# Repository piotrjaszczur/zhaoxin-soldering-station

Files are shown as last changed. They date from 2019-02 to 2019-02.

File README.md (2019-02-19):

# zhaoxin-soldering-station
Project for microcontrollers course at AGH. Soldering station control unit for the Zhaoxin 936 soldering iron

The schematic and the board created for the project for the microcontrollers course at AGH. 
It was based around the "Blue Pill" STM32 Development Board with STM32f103c8t6 MCU. It provided the temperature reading based on the ADC measuring of the voltage on the soldering iron termistor. IRF4905 PMOS transistor was driven by the PWM signal with the duty cycle depending on the current temperature reading. The rotary encoder allowed to change the desired temperature and the 4 microswitches allowed to choose one of the preset 4 different temperatures.

It is planned to be used with a 24V switching power supply.

stacja schem

stacja board

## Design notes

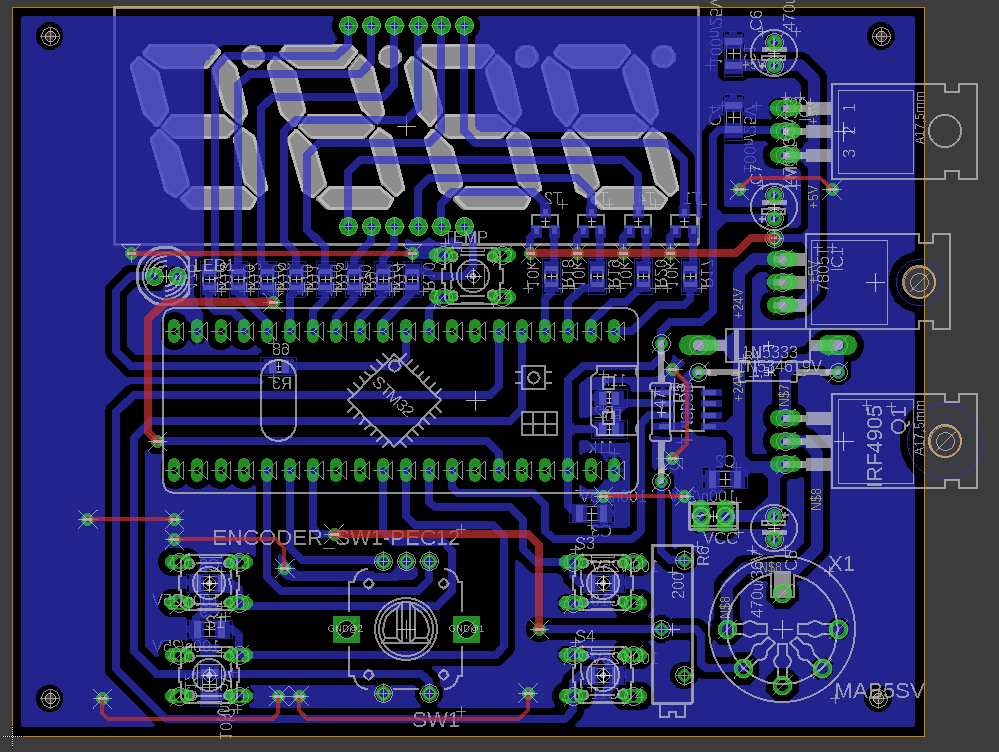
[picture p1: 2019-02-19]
stacja board.png

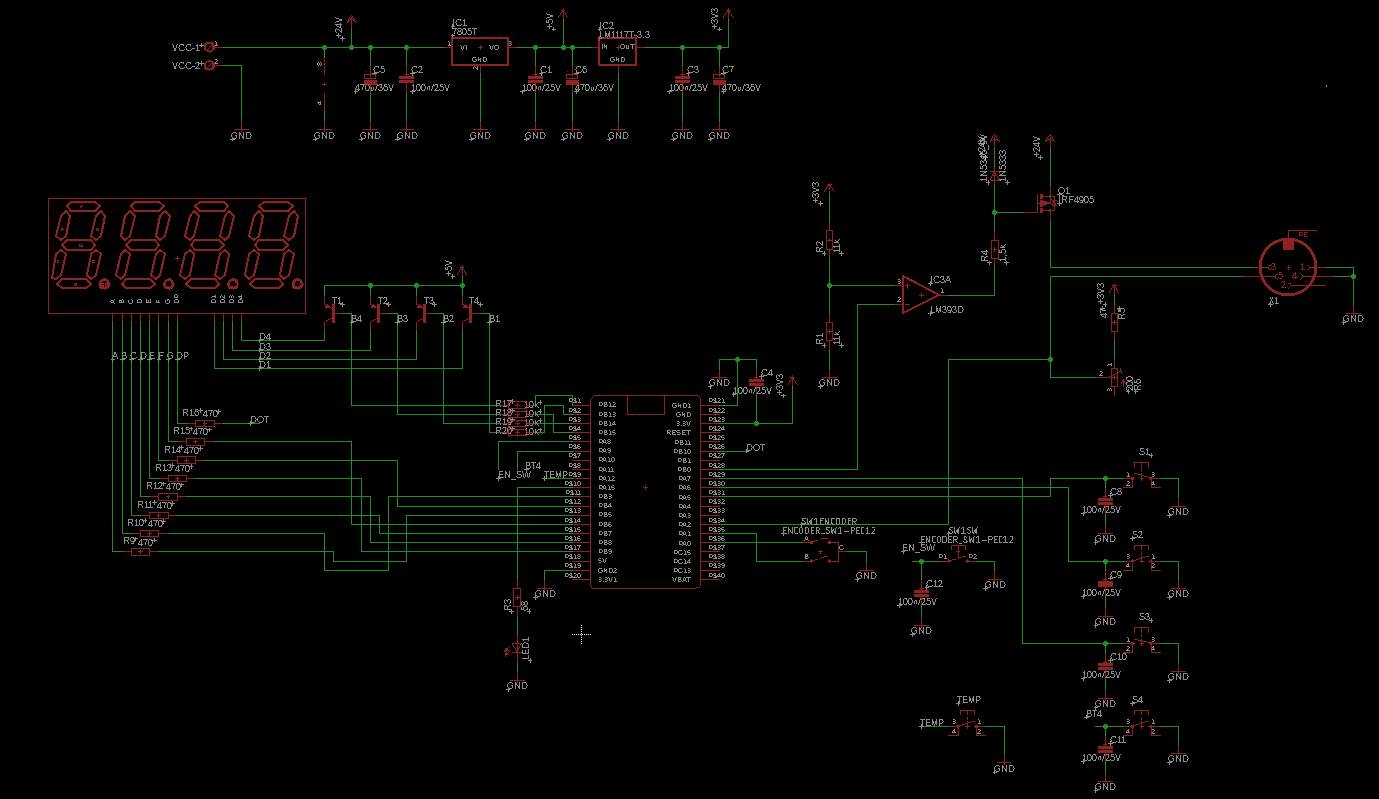
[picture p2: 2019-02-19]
stacja schem.png

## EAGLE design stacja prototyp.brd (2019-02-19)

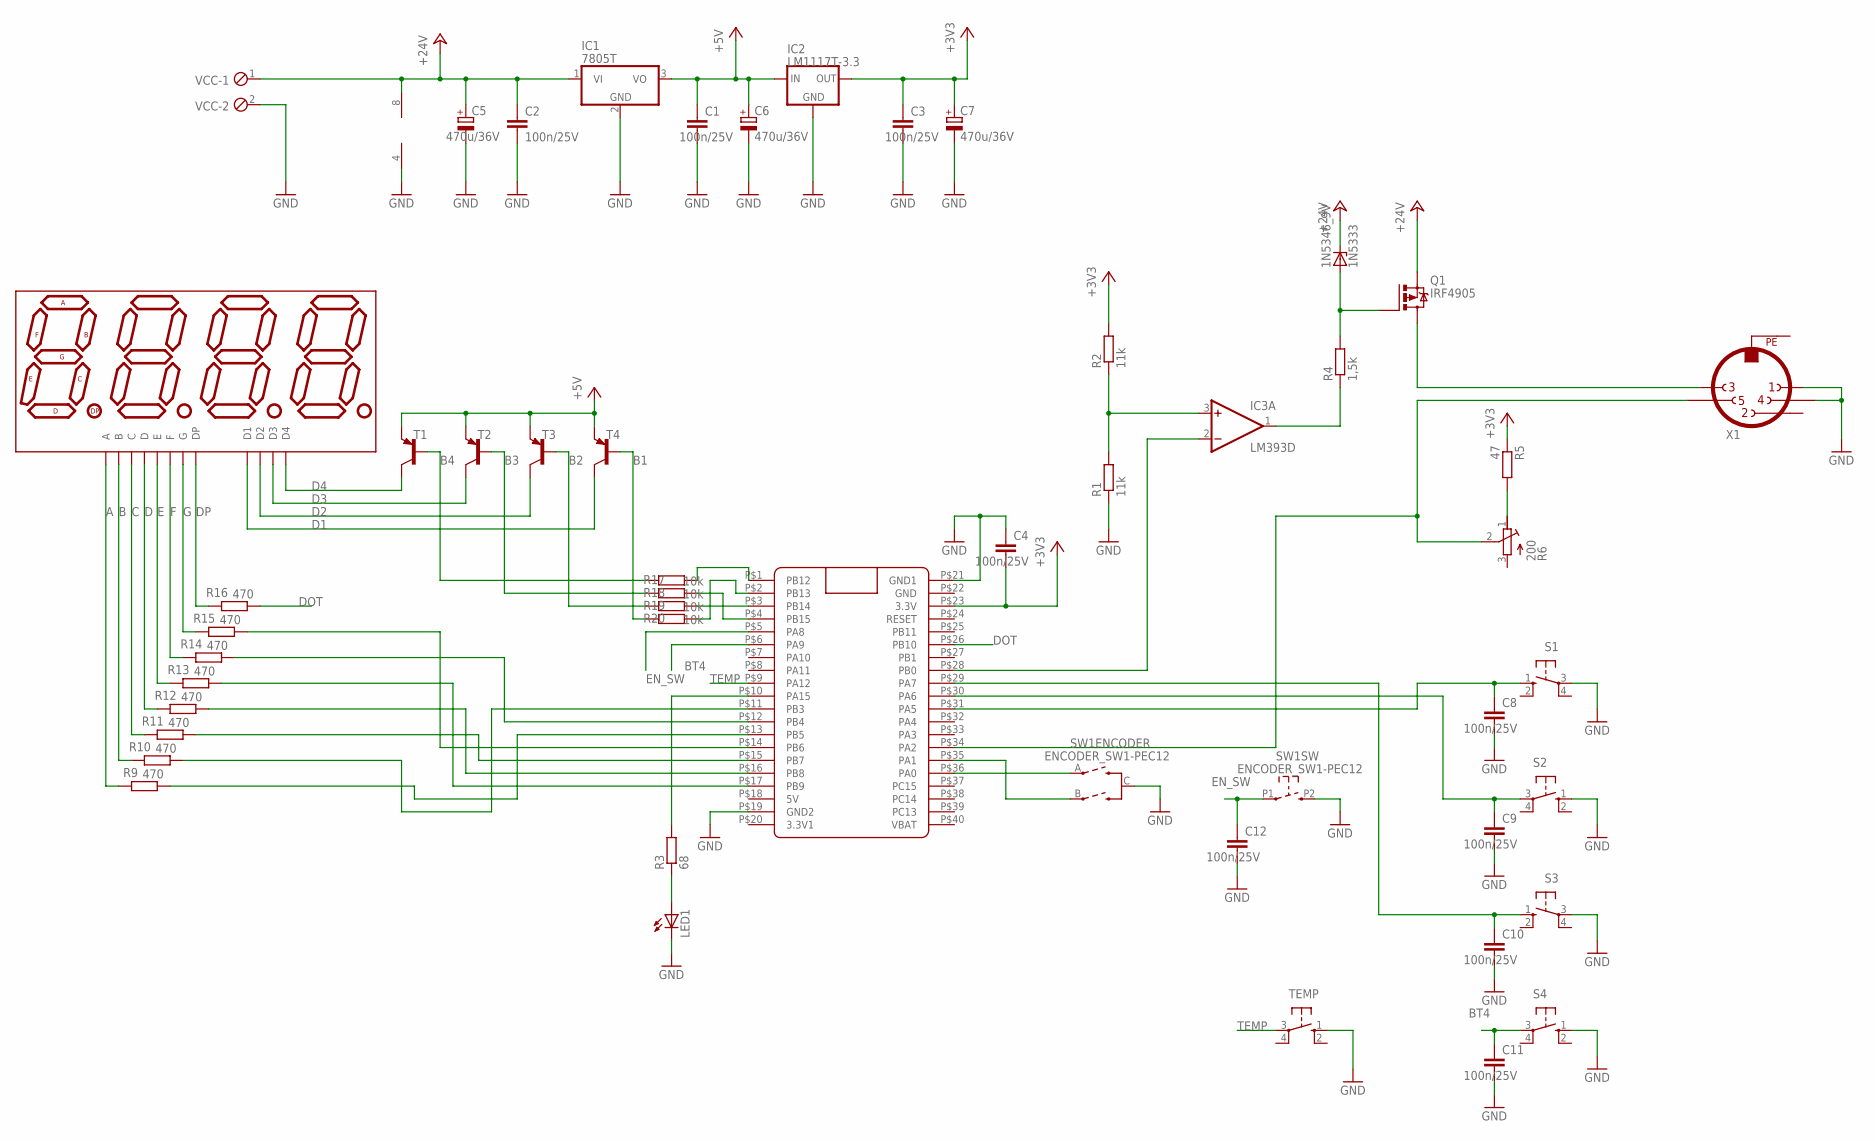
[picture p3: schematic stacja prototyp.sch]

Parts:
1N5346_9V: 1N5333; C1702-15
C1, C2, C3, C4, C8, C9, C10, C11, C12: 100n/25V; C1206
C5, C6, C7: 470u/36V; E2,5-5
DISP1: ATA8041ARBJ; 7-SEGMENT-4DIGIT-20MM
IC1: 7805T; TO220H
IC2: LM1117T-3.3; TO220
IC3: LM393D; SO08
LED1: LED5MM
Q1: IRF4905; TO220BH
R1, R2: 11k; R0805
R3: 68; R0805
R4: 1,5k; 0207/15
R5: 47; 0207/15
R6: 200; RTRIM43P
R9, R10, R11, R12, R13, R14, R15, R16: 470; M0805
R17, R18, R19, R20: 10k; M0805
S1, S2, S3, S4: 10-XX; B3F-10XX
SW1: ENCODER_SW1-PEC12; PEC12_INCREMENTAL_ENCODER
T1, T2, T3, T4: BC857B-PNP-SOT23-BEC; SOT23-BEC
TEMP: 10-XX; B3F-10XX
U$1: BLUE_PILL
VCC: MPT2; 2POL254
X1: MAB5SV

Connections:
+3V3: C3.1, C4.2, C7.+, IC2.2 (OUT), R2.2, R5.1, U$1.P$23 (3.3V)
+5V: C1.1, C6.+, IC1.3 (VO), IC2.3 (IN), T1.E, T2.E, T3.E, T4.E
+24V: 1N5346_9V.C, C2.1, C5.+, IC1.1 (VI), IC3.8 (V+), Q1.S, VCC.1
A: DISP1.11 (A), R9.2
B: DISP1.7 (B), R10.2
B1: R20.2, T4.B
B2: R19.2, T3.B
B3: R18.2, T2.B
B4: R17.2, T1.B
BT4: C11.1, S4.3, U$1.P$6 (PA9)
C: DISP1.4 (C), R11.2
D: DISP1.2 (D), R12.2
D1: DISP1.12 (D1), T4.C
D2: DISP1.9 (D2), T3.C
D3: DISP1.8 (D3), T2.C
D4: DISP1.6 (D4), T1.C
DOT: R16.1, U$1.P$26 (PB10)
DP: DISP1.3 (DP), R16.2
E: DISP1.1 (E), R13.2
EN_SW: C12.1, SW1.P1 (1), U$1.P$5 (PA8)
F: DISP1.10 (F), R14.2
G: DISP1.5 (G), R15.2
GND: C1.2, C2.2, C3.2, C4.1, C5.-, C6.-, C7.-, C8.2, C9.2, C10.2, C11.2, C12.2, IC1.2 (GND), IC2.1 (GND), IC3.4 (V-), LED1.K (C), R1.1, S1.3, S2.1 (S), S3.3, S4.1 (S), SW1.C, SW1.P2 (2), TEMP.1 (S), U$1.P$19 (GND2), U$1.P$21 (GND1), VCC.2, X1.1, X1.4
unnamed: IC3.2 (-IN), U$1.P$28 (PB0)
unnamed: C8.1, S1.1 (S), U$1.P$31 (PA5)
unnamed: C9.1, S2.3, U$1.P$30 (PA6)
unnamed: IC3.3 (+IN), R1.2, R2.1
unnamed: R6.2 (S), U$1.P$34 (PA2), X1.5
unnamed: IC3.1 (OUT), R4.1
unnamed: 1N5346_9V.A, Q1.G, R4.2
unnamed: Q1.D, X1.3
unnamed: SW1.A, U$1.P$36 (PA0)
unnamed: SW1.B, U$1.P$35 (PA1)
unnamed: LED1.A, R3.1
unnamed: R3.2, U$1.P$10 (PA15)
unnamed: R5.2, R6.1 (E)
unnamed: C10.1, S3.1 (S), U$1.P$29 (PA7)
unnamed: R18.1, U$1.P$4 (PB15)
unnamed: R19.1, U$1.P$3 (PB14)
unnamed: R17.1, U$1.P$1 (PB12)
unnamed: R20.1, U$1.P$2 (PB13)
unnamed: R13.1, U$1.P$17 (PB9)
unnamed: R12.1, U$1.P$16 (PB8)
unnamed: R11.1, U$1.P$15 (PB7)
unnamed: R15.1, U$1.P$14 (PB6)
unnamed: R9.1, U$1.P$13 (PB5)
unnamed: R14.1, U$1.P$12 (PB4)
unnamed: R10.1, U$1.P$11 (PB3)
PE: X1.PE
TEMP: TEMP.3, U$1.P$9 (PA12)

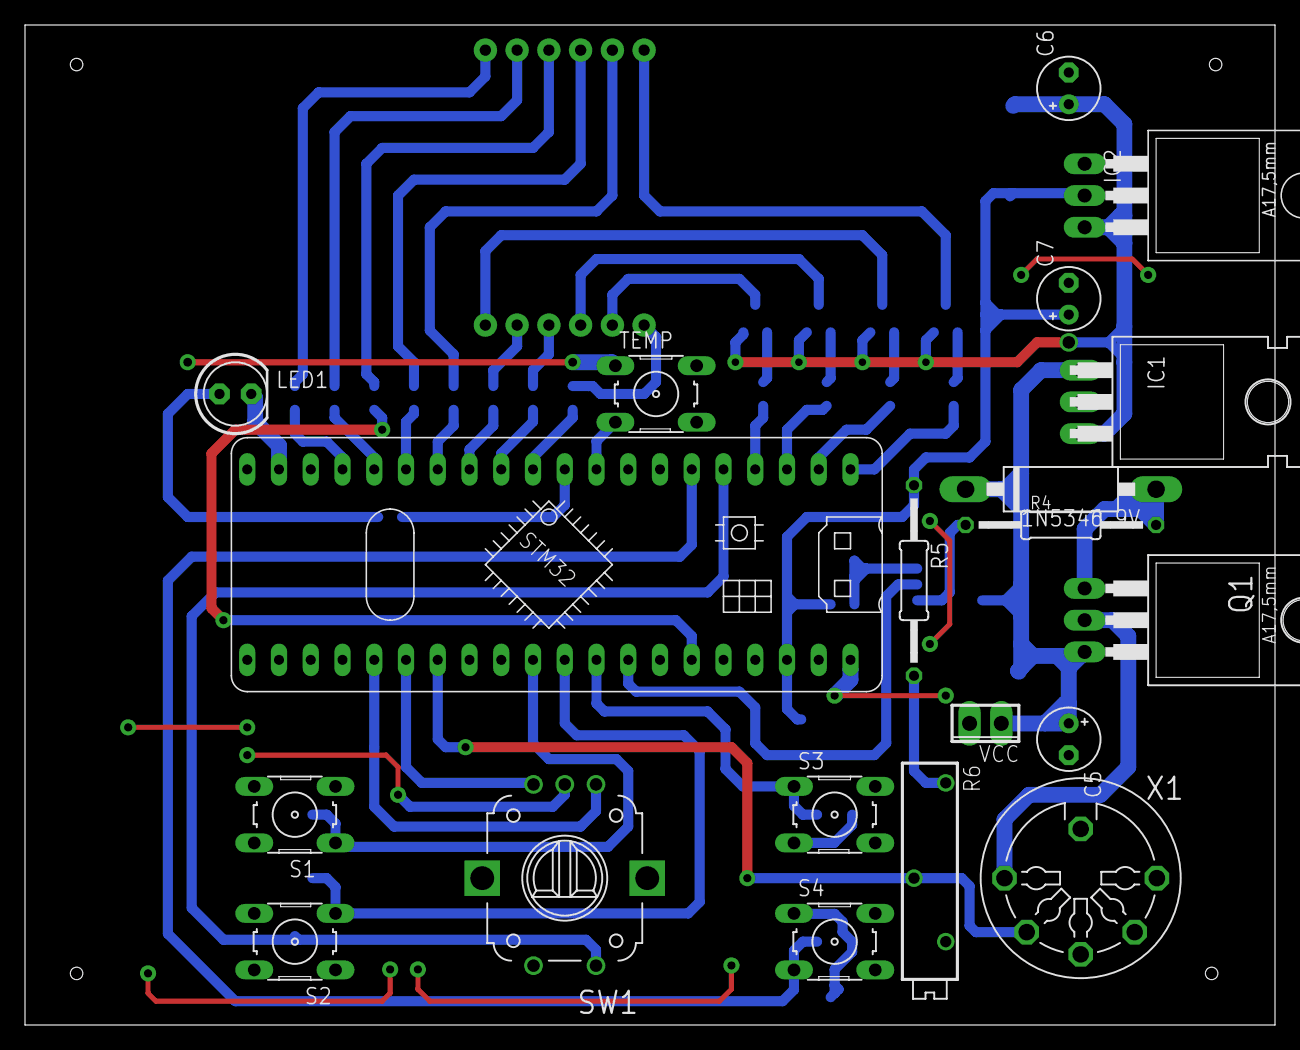
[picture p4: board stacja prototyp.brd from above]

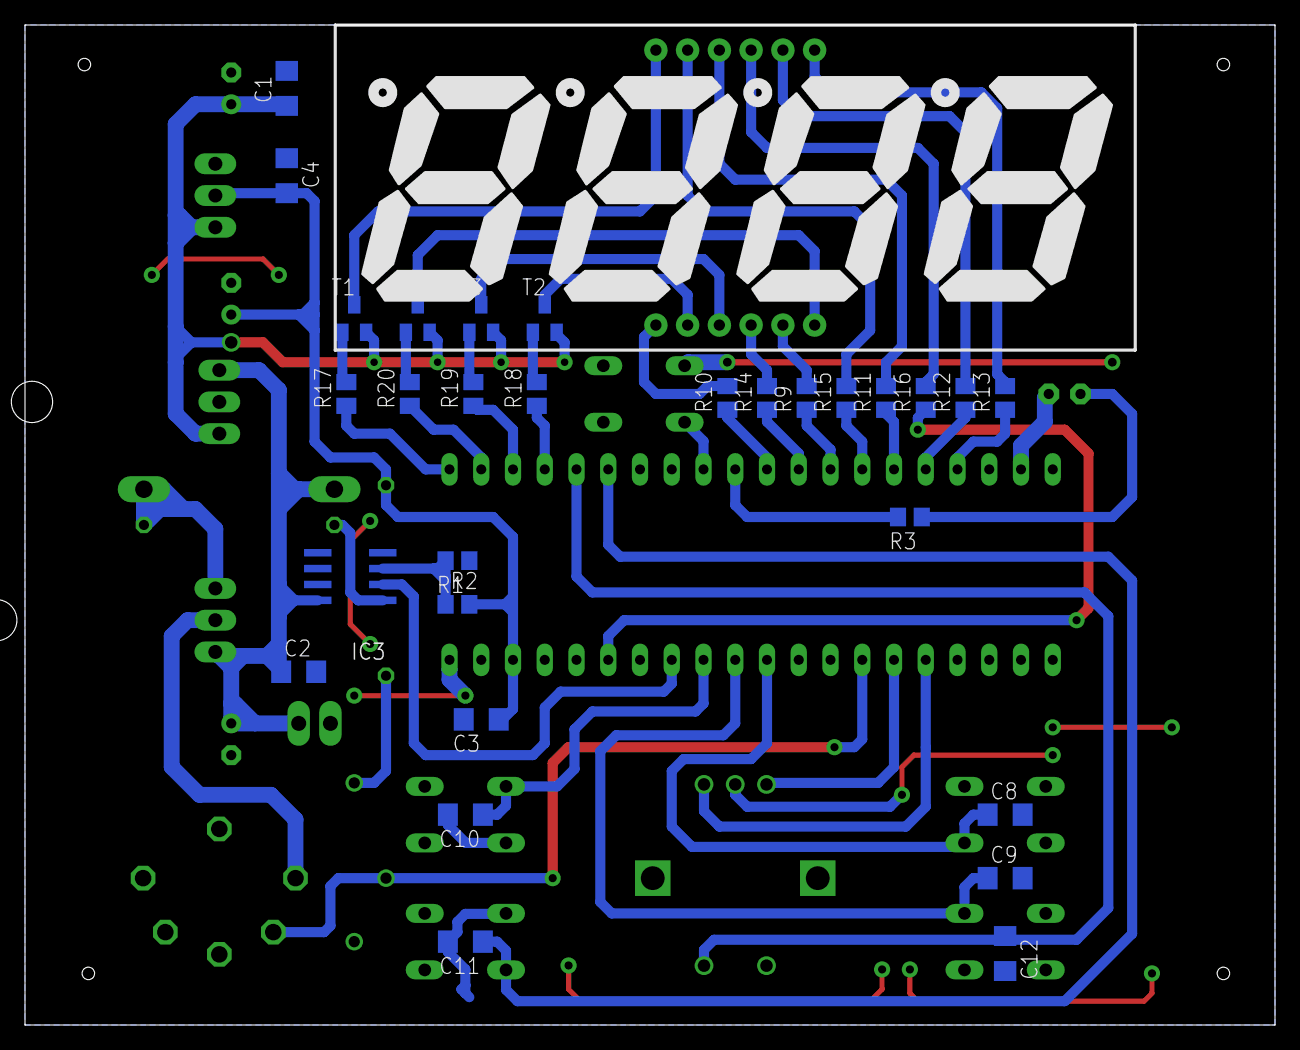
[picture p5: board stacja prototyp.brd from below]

Board: 2 copper layers, 100.0 x 80.0 mm, 50 parts (30 on the bottom side), 49 nets.

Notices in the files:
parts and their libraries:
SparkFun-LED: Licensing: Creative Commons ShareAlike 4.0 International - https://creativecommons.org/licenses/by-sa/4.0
